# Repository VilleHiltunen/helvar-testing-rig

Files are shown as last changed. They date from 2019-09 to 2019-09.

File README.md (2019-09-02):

# helvar-testing-rig

This repository is for holding software and other project artifacts from the Aalto-University protopaja 2019 course
from project group 4. Everything here is under the Creative Commons Attribution 4.0 International License, with two 
exceptions: The KiCAD Arduino board symbols and footprints which are licensed under LGPL under the name of 
Nicholas Parks Young at https://github.com/Alarm-Siren/arduino-kicad-library. The original readme can be found in 
the MegaShield folder.

The second exception is the software code, which is written under the MIT license, and is totally free for grabs.

NOTE: There is a current (01.09.2019) bug in the Windows Arduino AVR compiler, so the Arduino mega code might not compile
with the latest board definitions. This can be fixed by downgrading the board definitions from the boards manager. See:
https://arduino.stackexchange.com/questions/58495/strange-compiler-error-segmentation-fault

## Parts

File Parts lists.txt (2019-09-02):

Part lists
Frame:
4x 800mm length piece
4x 900mm length piece
4x 1200mm length piece
4x  3-way corner connector pieces
12x M8x30 hex-key bolts
4x plastic covers for 3-way corner pieces
8x 90° profile connector pieces
4x profile end cover pieces

Movement system:
2x Trinamic PD42-3-1141
1x some stepper motor found at sähköpaja
2x sliders for i-type aluminium profile
6x micro switches for limit switches
35mm Jopo quick release seat fastener
400*17mm aluminium pipe
15.5*25*8mm Linear bearing
4x 15*24*8mm Linear bearing
6x 24 tooth 3M pulleys with 8mm bore
2x 24 tooth 3M pulleys with 6mm bore
2x 6mm into 5mm pulley bore reducer
3M 88 tooth timing belt
7m piece of 3M timing belt cut into suitable length pieces
2x 915*8mm round steel shaft
2x 850*8mm round steel shaft
891*8mm round steel shaft
108*8mm round steel shaft
15*8mm round steel shaft
2x aluminium mounts for support rail
3d printed pieces (see sensor_testing_rig_asm.stp for details)
3mm acrylic laser cut pieces (see sensor_testing_rig_asm.stp for details)
Lots of nuts and bolts

Testin unit:
3 mm acrylic (plastic).
0.6 mm PCB
Pin header 1*5 (R2.54) 
P0900 analog micro servo (K-Power).
Aluminium rod (diameter 19 mm or larger).
33 ohm resistor (Royal Ohm).
3 mm threaded rod (steel).
2x M2*10mm screw
2x M2 nut
2x M3*4mm screw
4x M3 nyloc nut
2x M4*20mm screw (countersunk head)
M4 nyloc nut
M4 nylon tightening nut
small zip tie
heat-shrink tubing
0.8 mm steel wire (to attach head to the servo) 
insulated copper wire
3x small neodym magnets

Base plate:
64x avx 3 way 9155 standard battery connector
32x 0.5A reed switch
32x 1A reed switch
64 magnets
4x backbone pcb
32x mounting slot pcb
8 core 2.54 pitch flat cable
32 core 1.27 pitch flat cable
cable
laser cut acrylic pieces
32x cat shaped handles

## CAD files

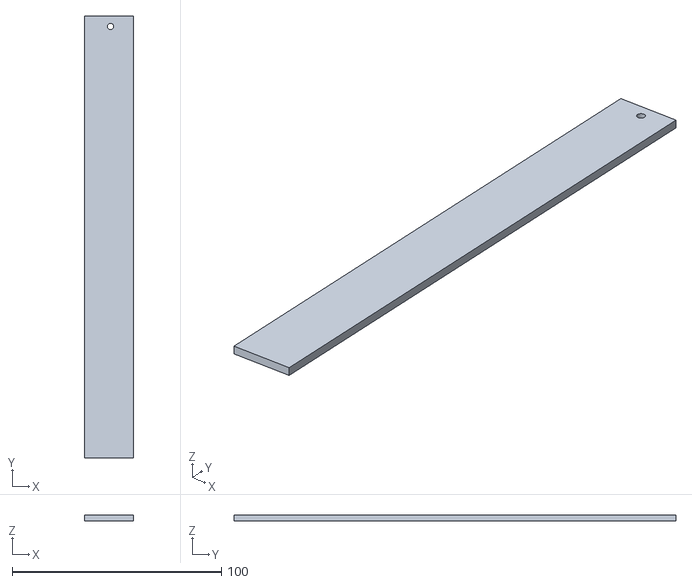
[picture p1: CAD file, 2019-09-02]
Board_stl/Assembly 1 - Part 4.stl
23.5 x 211.0 x 3.00

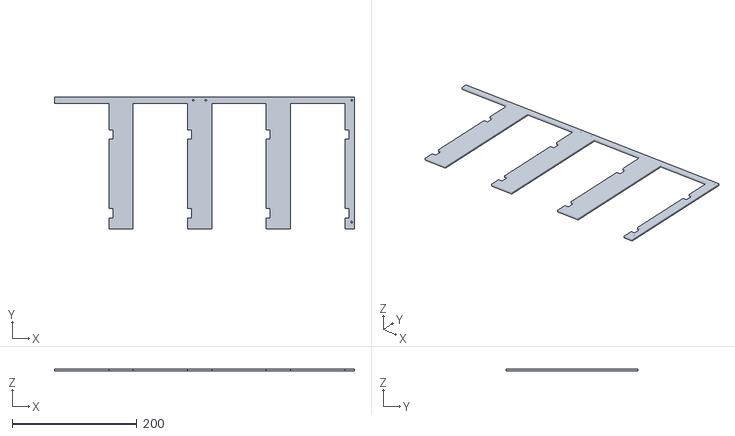
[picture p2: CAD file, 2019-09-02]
Board_stl/Assembly 1 - Part 2.stl
480.5 x 211.0 x 3.00

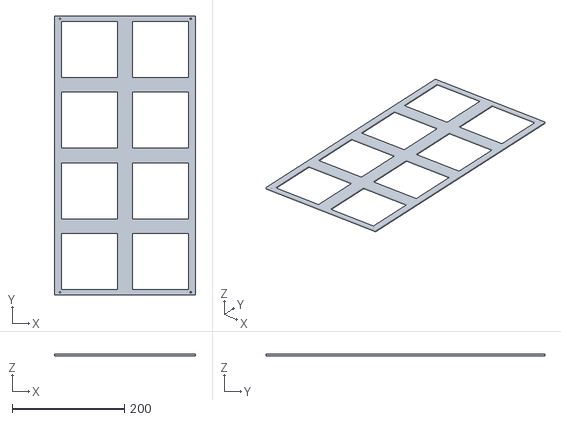
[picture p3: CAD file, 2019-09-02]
Board_stl/Assembly 1 - Part 6.stl
252.0 x 498.0 x 3.00

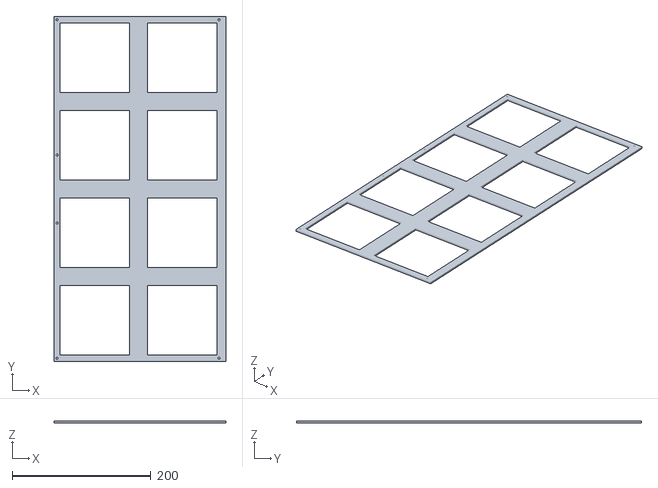
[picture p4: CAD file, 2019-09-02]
Board_stl/Assembly 1 - Part 5.stl
248.0 x 498.0 x 3.00

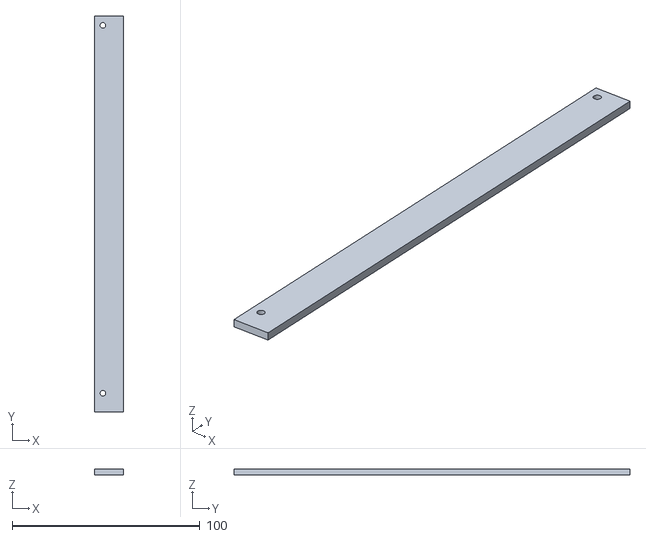
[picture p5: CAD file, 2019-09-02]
Board_stl/Assembly 1 - Part 3.stl
15.5 x 211.0 x 3.00

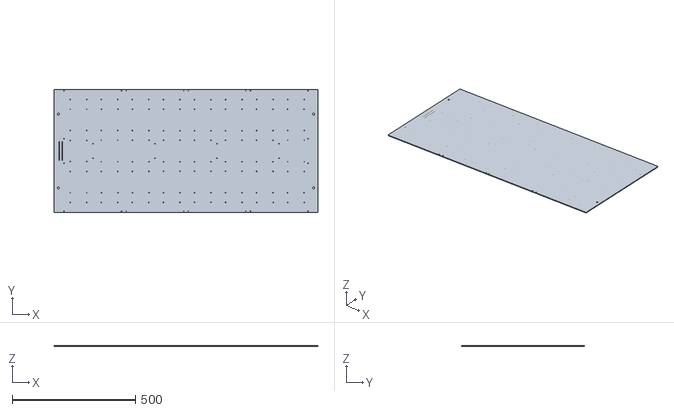
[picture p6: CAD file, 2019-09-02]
Board_stl/Assembly 1 - Part 1.stl
1072.0 x 498.0 x 3.00

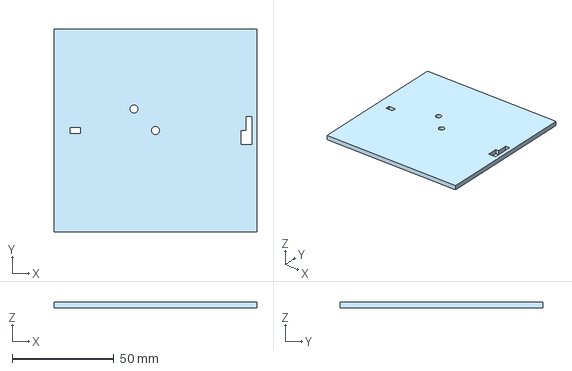
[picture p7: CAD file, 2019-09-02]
Testing_unit/Base/upper_plate.step
100.0 x 100.0 x 3.00 mm

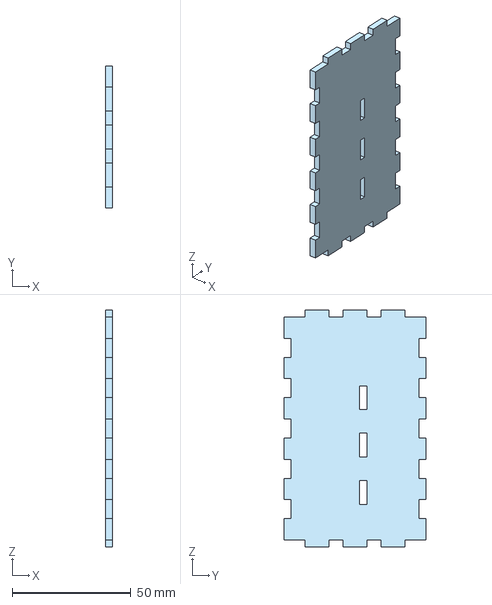
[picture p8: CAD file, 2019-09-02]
Testing_unit/Body/Body_100mm/side_100mm.step
3.00 x 60.0 x 100.0 mm

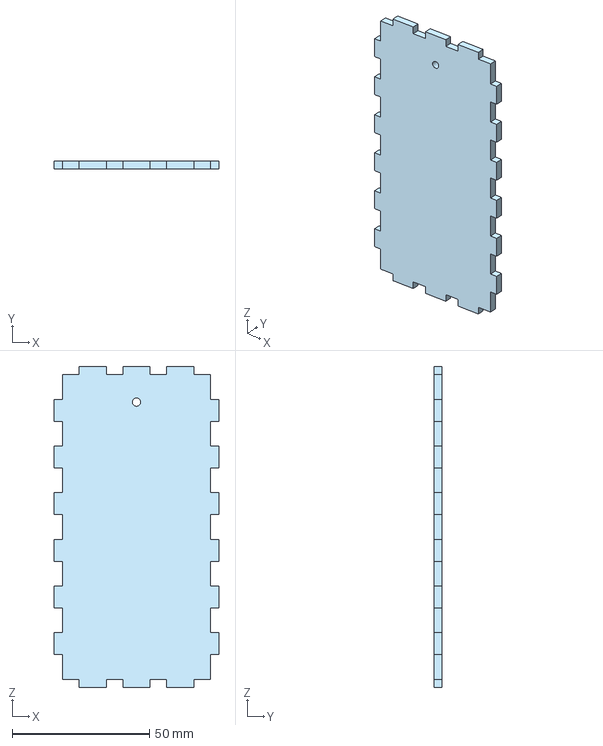
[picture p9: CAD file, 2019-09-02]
Testing_unit/Body/Body_117mm/front_117mm.step
60.0 x 3.00 x 117.0 mm

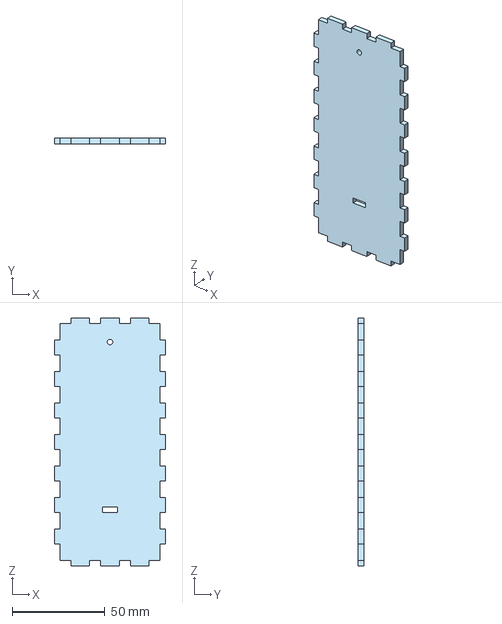
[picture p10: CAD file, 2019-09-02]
Testing_unit/Body/Body_134mm/back_134mm.step
60.0 x 3.00 x 134.0 mm

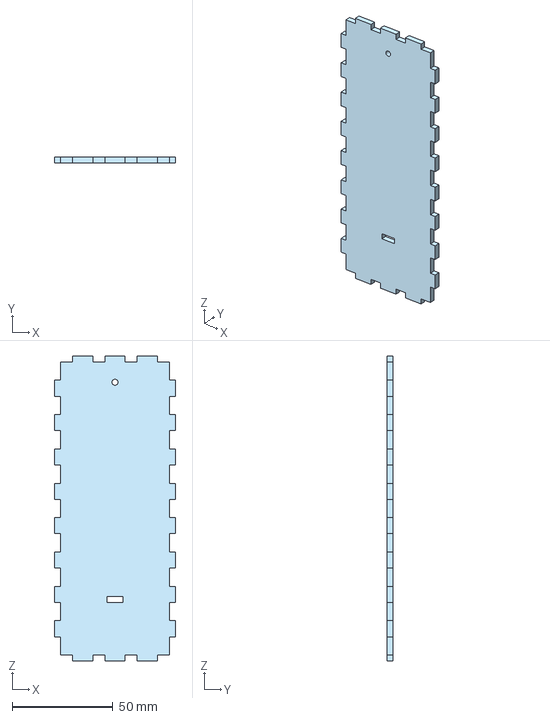
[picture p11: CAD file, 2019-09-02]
Testing_unit/Body/Body_151mm/back_151mm.step
60.0 x 3.00 x 151.0 mm

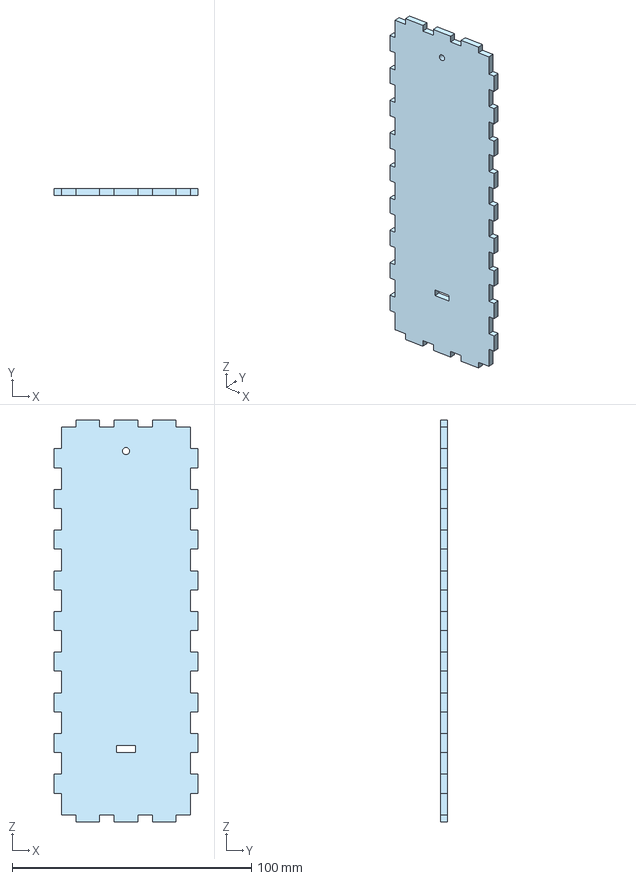
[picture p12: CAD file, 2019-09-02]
Testing_unit/Body/Body_168mm/back_168mm.step
60.0 x 3.00 x 168.0 mm

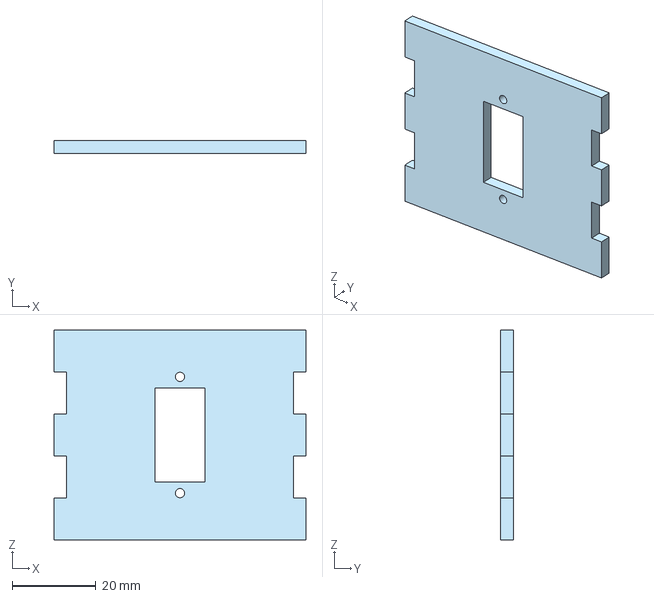
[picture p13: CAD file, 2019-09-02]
Testing_unit/Body/Common parts/servo_holder.step
60.0 x 3.00 x 50.0 mm

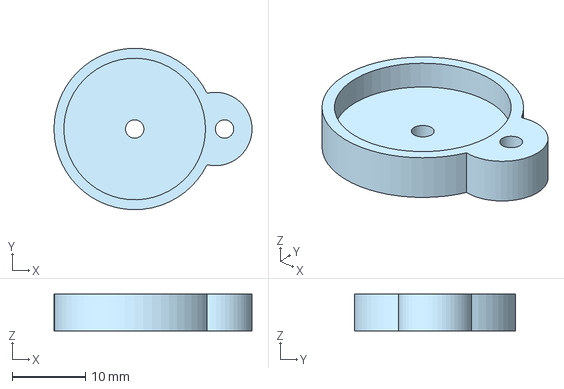
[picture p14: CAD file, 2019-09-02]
Testing_unit/Head/cap.step
27.0 x 22.0 x 5.00 mm

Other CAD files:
frame_cad/sensor_mounting_plate.stp
Testing_unit/Base/lower_plate.step
Testing_unit/Body/Body_100mm/back_100mm.step
Testing_unit/Body/Body_117mm/back_117mm.step
Testing_unit/Body/Body_100mm/front_100mm.step
Testing_unit/Body/Body_117mm/side_117mm.step
Testing_unit/Body/Body_134mm/front_134mm.step
Testing_unit/Body/Body_134mm/side_134mm.step
Testing_unit/Body/Body_151mm/front_151mm.step
Testing_unit/Body/Body_151mm/side_151mm.step
Testing_unit/Body/Body_168mm/front_168mm.step
Testing_unit/Body/Body_168mm/side_168mm.step
Testing_unit/Body/Common parts/bottom_plate.step
Testing_unit/Body/Common parts/top_plate.step
Testing_unit/Head/head.step
Testing_unit/Head/head_holder.step
frame_cad/M8_hex_nut_holder_for_aluminium_profile.stl
frame_cad/M8_hex_nut_holder_for_aluminium_profile.stp

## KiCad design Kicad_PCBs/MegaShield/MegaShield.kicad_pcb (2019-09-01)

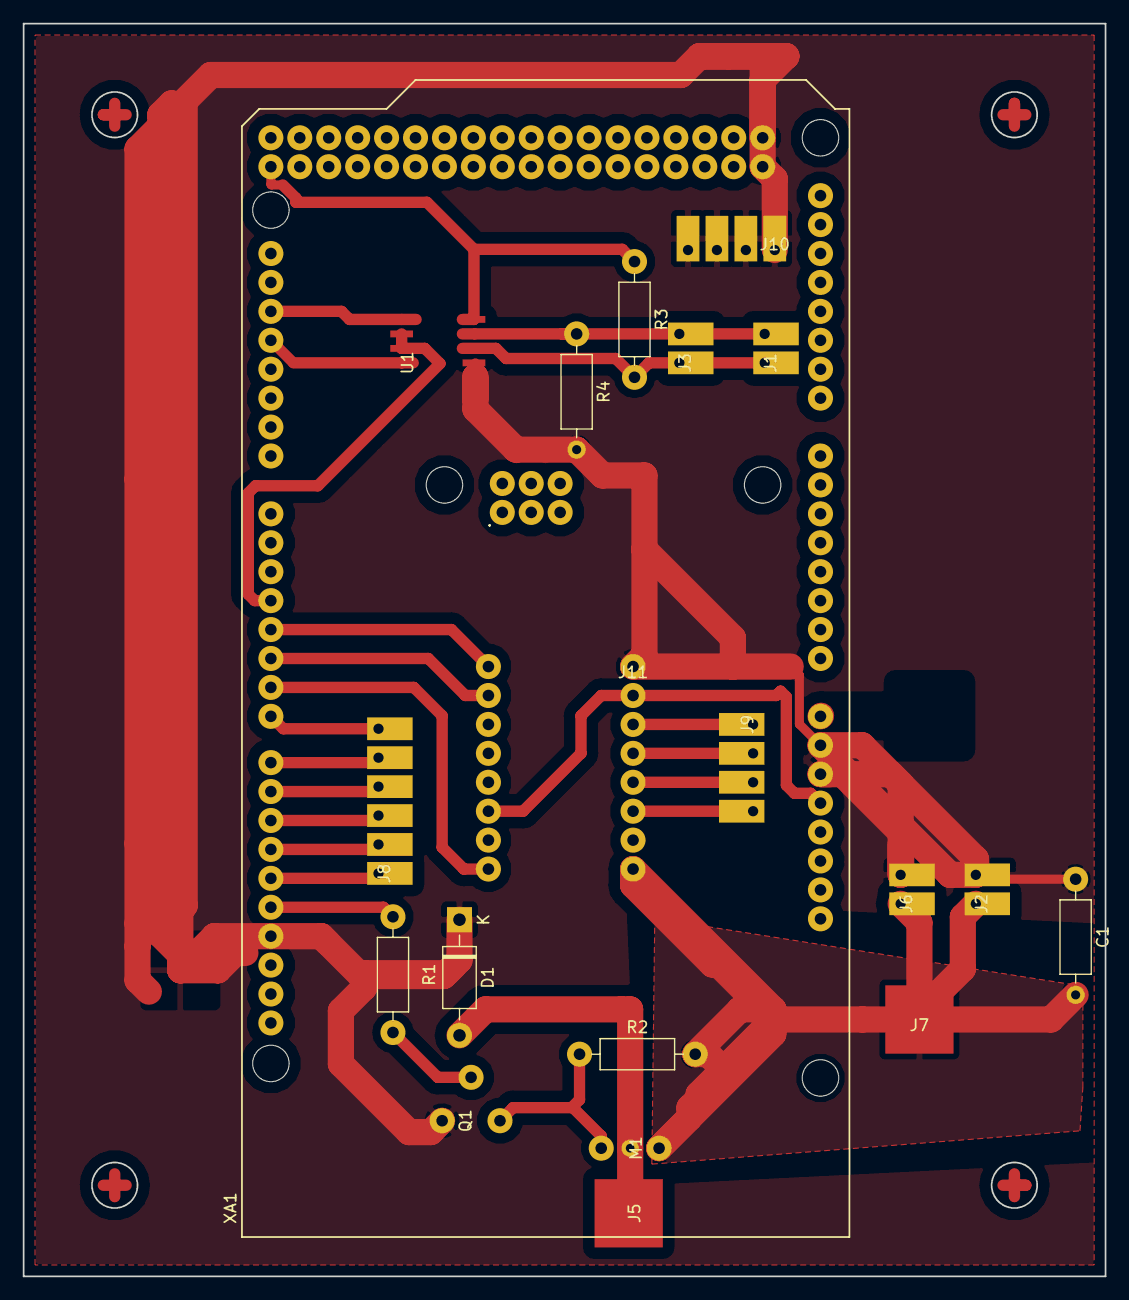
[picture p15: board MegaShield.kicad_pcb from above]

Board: 2 copper layers, 95.0 x 110.0 mm, 20 parts (0 on the bottom side), 25 nets.

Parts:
C1: 47u; R_Axial_DIN0207_L6.3mm_D2.5mm_P10.16mm_Horizontal
D1: DIODE; D_DO-41_SOD81_P10.16mm_Horizontal
J1, J3: rs485conn; 2_2.54
J2: Ypow; 2_2.54
J5: HeatingOut; VinPad
J6: Xpow; 2_2.54
J7: 12V_VIN; VinPad
J8: SensorLimits; 6_2.54
J9: SenStepper; 4_2.54
J10: limitSwitches; 4_2.54
J11: tmc2208; StepStick
M1: FQP27P06; MOSFET
Q1: 2N3904; BJT
R1: 10k; R_Axial_DIN0207_L6.3mm_D2.5mm_P10.16mm_Horizontal
R2: 1k; R_Axial_DIN0207_L6.3mm_D2.5mm_P10.16mm_Horizontal
R3, R4: R; R_Axial_DIN0207_L6.3mm_D2.5mm_P10.16mm_Horizontal
U1: MAX1487E; NSOIC-8
XA1: Arduino_Mega2560_Shield

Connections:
5V: J11.2, J11.14, R3.1, U1.8, XA1.5V1, XA1.5V3, XA1.5V4
12V: C1.2, J2.1, J6.1, J7.1, J11.8, M1.3, R2.2
DIR: J11.9, XA1.D4
DR: U1.2, U1.3, XA1.D3
EN: J11.16, XA1.D6
GND: C1.1, D1.1, J2.2, J6.2, J10.1, J10.2, J10.3, J10.4, J11.1, Q1.1, R4.2, U1.5, XA1.GND1, XA1.GND2, XA1.GND3, XA1.GND5, XA1.GND6
HEAT: R1.1, XA1.D13
unnamed: D1.2, J5.1, M1.1
unnamed: J1.1, J3.1, R3.2, U1.6
unnamed: J1.2, J3.2, R4.1, U1.7
unnamed: J9.1, J11.3
unnamed: J9.2, J11.4
unnamed: J9.3, J11.5
unnamed: J9.4, J11.6
unnamed: M1.2, Q1.3, R2.1
unnamed: Q1.2, R1.2
unnamed: U1.1, XA1.D18
unnamed: U1.4, XA1.D19
SEN_LL: J8.5, XA1.D8
SEN_RL: J8.6, XA1.D7
STEP: J11.10, XA1.D5
X_LL: J8.3, XA1.D10
X_RL: J8.4, XA1.D9
Y_LL: J8.1, XA1.D12
Y_RL: J8.2, XA1.D11

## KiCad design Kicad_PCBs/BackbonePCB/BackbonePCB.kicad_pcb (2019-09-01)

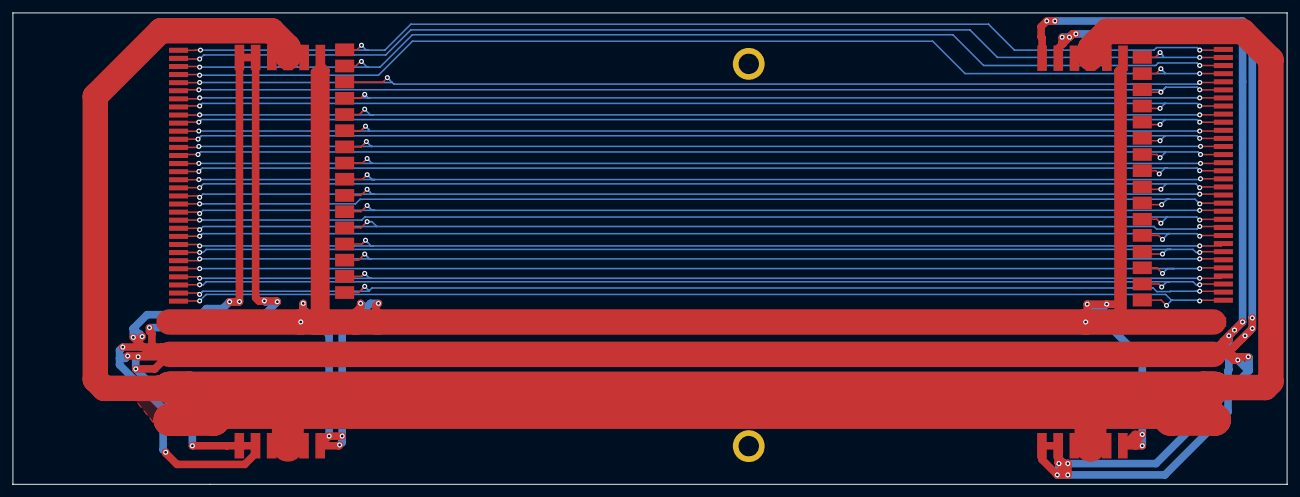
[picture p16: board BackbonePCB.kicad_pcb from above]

Board: 2 copper layers, 200.0 x 74.0 mm, 14 parts (0 on the bottom side), 35 nets.

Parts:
H1, H2: MountingHole; Screw_Hole
J1, J2, J7, J8: Conn_01x02_Female; SMD_Connector_2X
J3, J4, J5, J6: Conn_01x06_Female; SMD_Connector_6X
J9, J12: Conn_01x32_Female; Connector_32x
J10, J11: Conn_01x16_Female; Connector_16x

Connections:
/5V: J2.2, J3.6, J4.1, J5.6, J6.1, J8.1
/12V: J2.1, J3.1, J3.2, J4.5, J4.6, J5.1, J5.2, J6.5, J6.6, J8.2
/GND: J1.1, J1.2, J3.3, J3.4, J3.5, J4.2, J4.3, J4.4, J5.3, J5.4, J5.5, J6.2, J6.3, J6.4, J7.1, J7.2
unnamed: J9.32, J10.1, J12.1
unnamed: J9.30, J10.2, J12.3
unnamed: J9.28, J10.3, J12.5
unnamed: J9.26, J10.4, J12.7
unnamed: J9.24, J10.5, J12.9
unnamed: J9.22, J10.6, J12.11
unnamed: J9.20, J10.7, J12.13
unnamed: J9.18, J10.8, J12.15
unnamed: J9.16, J10.9, J12.17
unnamed: J9.14, J10.10, J12.19
unnamed: J9.12, J10.11, J12.21
unnamed: J9.10, J10.12, J12.23
unnamed: J9.8, J10.13, J12.25
unnamed: J9.6, J10.14, J12.27
unnamed: J9.4, J10.15, J12.29
unnamed: J9.2, J10.16, J12.31
unnamed: J9.1, J11.1, J12.32
unnamed: J9.3, J11.2, J12.30
unnamed: J9.5, J11.3, J12.28
unnamed: J9.7, J11.4, J12.26
unnamed: J9.9, J11.5, J12.24
unnamed: J9.11, J11.6, J12.22
unnamed: J9.13, J11.7, J12.20
unnamed: J9.15, J11.8, J12.18
unnamed: J9.17, J11.9, J12.16
unnamed: J9.19, J11.10, J12.14
unnamed: J9.21, J11.11, J12.12
unnamed: J9.23, J11.12, J12.10
unnamed: J9.25, J11.13, J12.8
unnamed: J9.27, J11.14, J12.6
unnamed: J9.29, J11.15, J12.4
unnamed: J9.31, J11.16, J12.2

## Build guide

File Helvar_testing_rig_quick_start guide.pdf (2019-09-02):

# Helvar testing rig quick start guide

Ville Hiltunen
02.09.2019
1. Plug both the 12V and 5V power adapters into the machine. Plugging the connectors into the wrong plugs won’t cause electrical problems, but the machine won’t turn on.
2. Turn on the power switch. The xy-plane stepper motors should now blink their LEDs. If not, check power adapters.
3. Connect the Arduino to the device.
4. Open a serial connection with Arduino. Baud rate should be 38400 unless modified. The Arduino serial monitor has been tested to work, but in theory any serial terminal should work.
5. The serial should display formatted replies from the motors. If not, you’ve ran into the mysterious bug that blocks communication on the RS-485 line. Try again later and/or after cycling the device power.
6. If replies are displayed on the screen, insert the command “homesen” (without the quotes) to home the sensor header. All commands should have a newline (‘\n’) as the end character.
7. Next, insert command “homexy” to home the XY-plane.
8. The device should now be ready to use! The command format for commands with arguments is cmd(arg1,arg2,...,argx).
9. Remove a cover from a slot, then place a model to the slot. The magnets should pull the model and the connector together. Use srva(slotnumber) to add the model. If everything went right, the servo should be waving back and forth and heating up. If not, either there is a problem with the connection or the model is misplaced. Use srvl to list servo locations. Note that the first slot starts from the corner where the Arduino usb plug is connected.

10.Try more commands from the list below.

## Command list and descriptions:

## Main functionalities:

Command word | Arguments | Description
homesen | 0 | Homes the sensor header to the middle position, which is set to be angle 0.
homexy | 0 | Homes the xy-plane. Note: This command will flush the command buffer, and while the device is homing, no new commands will be read from the buffer. At the end of homing, the sensor head will be placed above the corner of the simulated room, and this position will be considered (0,0) for millimeter coordinates.
xypos | 2 | Run the sensor head to a xy-position in millimeters. Argument 1: x-axis from 0 to 1000. Argumen 2: y-axis from 0 to 500. Example input: xypos(100,250)
sen | 1 | Turns the sensor head to the given angle. Input: Sensor angle relative to the 0 position from -125 to 125. If the sensor is unhomed, the sensor head might overshoot and hit a limit switch. If this happens, the device should be rehomed. Example input: sen(50)
help | 0 | Lists the commands, arguments and constraints to the serial line.
heatc | 1 | Sets the heating power as a percentage between 0 and 100. Example input: heatc(15)
heatl | 0 | Lists the current heating power.
heati | 0 | Activates full heating power for 60 seconds.
srva | 1 | Adds a model to the given slot. Accepts inputs from 1-32.

| | Example input: srva(1)
srvr | 1 | Removes a model from the given slot. Input: 1 to 32 or -1. Inputting -1 purges all servos. Example input: srvr(1) Bug: Current code allows 0 as a valid input, which results in an access outside of array bounds.
srvl | 0 | Lists the positions of models and speeds and hold delays of all slots.
srvs | 2 | Changes model swaying speed. Argument 1: The slot number from 1 to 32 or -1 for all models. Argument 2: The speed percentage from 1 to 100. The command displays the actual microsecond delay after input. Example input: srvs(-1,50) Bug: Current code allows 0 as a valid input, which results in an access outside of array bounds.
srvm | 2 | Sets the model to the given movement state. Argument 1: The slot number from 1 to 32 or -1 for all models. Argument 2: The new state, either 0 or 1. 0 for constant sway, 1 for delay at the max and min angles. Example input: srvm(1,1) Bug: Current code allows 0 as a valid input, which results in an access outside of array bounds.
srvh | 2 | Changes model holding delay. Default setting holds the model in place for 3 seconds at minimum and maximum angles. Argument 1: The slot number from 1 to 32 or -1 for all models. Argument 2: The hold in milliseconds from 5 to 30000. The command displays the actual microsecond delay after input. Example input: srvh(-1,2000)

Bug: Current code allows 0 as a valid input, which results in an access outside of array bounds.

## Trinamic stepper motor commands:

These commands are very similar to the Trinamic PD42 stepper commands and speak directly to the rig stepper motors. Care should be taken with these functions, as they might alter the behavior of the program.

Command word | Argument s | Description
mst | 1 | Stops the target motor. Argument is the motor address, either 1 or 2.
gap | 2 | Asks for a certain axis parameter from the driver. Argument 1 is the motor address, 1 or 2. Argument 2 is the command type, aka which parameter we are interested in , from 0 to 255. See trinamic documentation in references for details.
sap | 3 | Sets a certain axis parameter on the driver. Argument 1 is the motor address, 1 or 2. Argument 2 is the command type, aka which parameter we are interested in, from 0 to 255. Argument 3 is the value we want to set the parameter to. See trinamic documentation in references for details.
ggp | 3 | Asks for a certain global parameter from the driver. Argument 1 is the motor address, 1 or 2. Argument 2 is the command type, aka which parameter we are interested in, from 0 to 255. Argument 3 is the memory bank from 0 to 3. See trinamic documentation in references for details.
sgp | 4 | Sets a certain global parameter in the driver. Argument 1 is the motor address, 1 or 2. Argument 2 is the command type, aka which parameter we are interested in, from 0 to 255. Argument 3 is the memory bank from 0 to 3. Argument 4 is the new value for the parameter.

| | See trinamic documentation in references for details.
rfs | 2 | Controls the homing of the target motor. Argument 1 is the target motor, 1 or 2. Argument 2 is the command. 0 for starting, 1 for stopping and 2 for asking for status. See trinamic documentation in references for details.
exp | 5 | Not a true trinamic command, rather this command emulates a totally free form 8 byte package for sending to the motor drivers. Consult the firmware documentation and know exactly what you are doing before using this. Argument 1 is the target motor address. Argument 2 is the instruction number. Argument 3 is the type number. Argument 4 is the motor or bank number. Argument 5 is the value. Checksum is calculated automatically for the user.

## References

Trinamic PD42 stepper page. See the firmware manual for more info on stepper commands: https://www.trinamic.com/products/drives/stepper-pandrives-details/pd42-x-1141/

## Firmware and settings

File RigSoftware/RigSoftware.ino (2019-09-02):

/*
 * Written by Ville Hiltunen (2019) villejhiltunen@gmail.com under MIT license.
 */

#include "RigSoftware.h"
#include <Servo.h>

/*
 * Command definitions here. 
 * Type 1 corresponds to PANdrive stepper functions, 
 * Type 2 is servo related functions
 * Type 3 is for sensor movement
 * Type 4 is heating related functions
 * Type 5 is the type for the main composite functionalities that issue commands themselves and other miscallaneous control commands.
 * 
 * If you wish to add your own ones, add it here, go to the function that handles it and add a handler.
 * Also increment the COMMAND_LIST_SIZE by one. PANdrive stepper functions have a universal handler, provided a prefilled MI
 * and arg field is provided.
 * 
 * CMD is the command word recognized by the parser.
 * 
 * Len is the number of letters in the command word.
 * 
 * Args is the number of arguments the command has
 * 
 * Arg_Field is strictly for PANdrive stepper functions and guides which argument fills which datafield in the 9 byte command.
 *    arg_Field should be the size of the number of arguments for the command. Argument 0 uses the index of arg_field[0] and so forth.
 *    Index 0 is the machine address, Index 1 is the command type, Index 2 is the type specification, Index 3 is the motor bank and Index 4 is the 4-byte value.
 *    Check sendMotorCommand function for more details.
 *    
 * Lower and higher constraints limit the allowed user input between them. There should be as many constraints as there are arguments.
 * 
 * Prefilled MI is a motorInfo struct that has the correct command number associated with the command according to PANdrive manual. Not used for non PD-stepper functions.
 */
commandWordInfoStruct commandWordInfo[COMMAND_LIST_SIZE] = {
//Type	Cmd					Len	Args	arg_Field			Lower constraints			Higher constraints		Prefilled MI
	//{1,		"ror",			3,	2,		{0,4,},				{1,-2047,},						{2,2047,},						{0,1,},},
	{1,		"mst",			3,	1,		{0,},					{1,},									{2,},									{0,3,},},
	{1,		"mvp",			3,	2,		{0,4,},				{1,-2147483648,},			{2,2147483647,},			{0,4,},},
	{1,		"gap",			3,	2,		{0,2,},				{1,},									{2,255,},							{0,6,},},
	{1,		"ggp",			3,	3,		{0,2,3,},			{1,},									{2,255,3,},						{0,10,},},
	{1,		"sgp",			3,	4,		{0,2,3,4},		{1,0,0,-2147483647},	{2,255,3,2147483647},	{0,9,},},
	{1,		"sap",			3,	3,		{0,2,4,},			{1,0,-2147483648,},		{2,255,2147483647,},	{0,5,},},
	{1,		"rfs",			3,	2,		{0,2,},				{1,},									{2,255,3,},						{0,13,},},
	{1,		"stap",			4,	2,		{0,2,},				{1,},									{2,255,},							{0,7,},},
	{2,		"srva",			4,	1,		{0},					{1,},									{32,},},
	{2,		"srvr",			4,	1,		{0},					{-1,},								{32,},},
	{2,		"srvs",			4,	2,		{0,2,},				{-1,1,},							{32,100,},},
	{2,		"srvl",			4,	0,		},
	{2,		"srvm",			4,	2,		{0,},					{-1,0,},							{32,1,},},
	{2,		"srvh",			4,	2,		{0,},					{-1,5,},							{32,30000,},},
	{3,		"sen",			3,	1,		{0},					{-125,},							{125,},},
	{4,		"heatc",		5,	1,		{0},					{0},									{100},},
	{4,		"heatl",		5,	0,		},
	{4,		"heati",		5,	0,		},
	{5,		"xypos",		5,	2,		{0},					{0,0,},								{1000,500,},/*{-2147483648,-2147483648,},		{2147483647,2147483647,},*/},
	{5,		"homexy",		6,	0,		},
	{5,		"homesen",	7,	0,		},
	{5,		"help",			4,	0,		},
	{1,		"exp",			3,	5,		{0,1,2,3,4},	{0,0,0,0,-2147483647},{255,255,255,255,2147483647},					{0,},},
};

//Buffers, flags and struct inits.
char cmdBuffer[CMD_BUFFER_LEN];
char replyBuffer[CMD_BUFFER_LEN];
commandInfo cmdInfo;
commandInfo replyInfo;
int sensorTasklist[SENSOR_TASKLIST_LEN];
unsigned long timers[TIMER_LEN];
int replyFlag;
int servoModeFlag;
ringBufferInfoStruct ringBufferInfo;
servoInfoStruct servoInfo;
heatingInfoStruct heatingInfo;
homeInfoStruct homeInfo;

void setup() {
	Serial.begin(38400);
	Serial1.begin(38400);
	while (!Serial) {
		;
	}
  pinMode(DR_PIN, OUTPUT);
  pinMode(SENSOR_ENABLE, OUTPUT);
  pinMode(HEATING_PIN, OUTPUT);
  pinMode(SENSOR_DIR, OUTPUT);
  pinMode(SENSOR_STEP, OUTPUT);
  pinMode(SENSOR_LSWITCH, INPUT_PULLUP);
  pinMode(SENSOR_RSWITCH, INPUT_PULLUP);
  // Sadly there was no time to add the xy limit switches. RIP
  //pinMode(X_RSWITCH, OUTPUT);
  //pinMode(X_LSWITCH, OUTPUT);
  digitalWrite(SENSOR_ENABLE, HIGH);
  digitalWrite(SENSOR_DIR, LOW);
  digitalWrite(SENSOR_STEP, LOW);
	digitalWrite(DR_PIN,LOW);
  // Setting default values
	sensorTasklist[SENSOR_MAX] = 300;
	sensorTasklist[SENSOR_MIN] = -300;
	heatingInfo.heatingActual = map(HEATING_DEFAULT_PERCENT,0,100,0,200);
	heatingInfo.heatingPercent = HEATING_DEFAULT_PERCENT;
	cmdInfo.cmdBuffer = cmdBuffer;
	replyInfo.cmdBuffer = replyBuffer;
  // We initialize each servo position with -1, which means no servo.
  // Also, we attach and detach each servo position to prevent floating servo signals at startup.
	for (int i = 0; i < SERVO_SLOTS; i++) {
    servoInfo.servos[0].attach(i+1+SERVO_PIN_OFFSET);
		servoInfo.slots[i] = -1;
    delay(20);
    servoInfo.servos[0].detach();
	}
	for (int i = 0; i < SERVO_AMOUNT; i++) {
		servoInfo.states[i] = 1;
		servoInfo.delays[i] = SERVO_DEFAULT_DELAY_U;
		servoInfo.holdDelays[i] = SERVO_DEFAULT_HOLD_DELAY;
	}
	// Actual initialization of the machine. We set the proper speed for the machine, set the heating to max for 60 seconds
  // And we home the steppers
  injectCommand(ringBufferInfo, "heati");
  injectCommand(ringBufferInfo, "sap(1,4,400)");
  injectCommand(ringBufferInfo, "sap(2,4,200)");
  /*
  injectCommand(ringBufferInfo, "sap(1,194,2000)");
  injectCommand(ringBufferInfo, "sap(2,194,2000)");
  */
  /*
  injectCommand(ringBufferInfo, "sap(1,140,7)");
  injectCommand(ringBufferInfo, "sap(2,140,7)");
  */
  /*
  injectCommand(ringBufferInfo, "sap(1,140,7)");
  injectCommand(ringBufferInfo, "sap(2,140,7)");
  */
  //injectCommand(ringBufferInfo, "homexy");
	timers[LOOP_TIMER] = millis();
}

void loop() {
	// Check if serial line has data for us. It will be stored in the cmdInfo struct.
	if (!cmdInfo.newCmd && !(homeInfo.homeXFlag || homeInfo.homeYFlag)) {
		cmdInfo = getCommand(cmdInfo, Serial);
		if (replyInfo.errorNmbr) {
			// The command or the buffer had some error. Print complaint.
	  	Serial.print("Command buffer error -	");
	  	Serial.println(cmdInfo.errorNmbr);
	  	cmdInfo.errorNmbr = 0;
	  	cmdInfo.newCmd = 0;
	  	cmdInfo.dataIndex = 0;
	  }
	}
  // Check if the flag for a new command has been raised. (data contained a newline)
	if (cmdInfo.newCmd && !(homeInfo.homeXFlag || homeInfo.homeYFlag)) {
		// We have a new command. Copy it to our command ring buffer.
		injectCommand(ringBufferInfo,cmdInfo.cmdBuffer);
		cmdInfo.newCmd = 0;
		cmdInfo.dataIndex = 0;
	}
	// Process a command from the ringbuffer if there are any and we are not waiting.
	// Wait is issued when a command is sent to the XY-plan motors to reduce communication
	// errors.
	if (!replyFlag && ringBufferInfo.commandCount > 0) {
		String incCommand = grabRingBufferCommand(ringBufferInfo);
		parseResult result = evaluateCommand(incCommand, commandWordInfo, Serial);
		if (result.errorStatus) {
			Serial.print("Parsing error, code: ");
			Serial.println(result.errorStatus);
      if (result.errorStatus == E_COMMAND_MALFORMED) {
        Serial.println("Command malformed");
      }
			//Serial.println("Send command errl to list codes.");
		}
		else {
			switch (commandWordInfo[result.commandIndex].commandType) {
				case 1:
					sendMotorCommand(timers, result, commandWordInfo);			
					break;			
				case 2:
					sendServoCommand(timers, result, commandWordInfo, servoInfo, Serial);
					break;			
				case 3:
					sendSensorCommand(timers, result, commandWordInfo, sensorTasklist, Serial);
					break;		
				case 4:
					sendHeatingCommand(timers, result, commandWordInfo, heatingInfo, Serial);
					break;
				case 5:
					sendControlCommand(timers, result, commandWordInfo, ringBufferInfo, Serial, homeInfo, sensorTasklist);
					break;	
				default:
					Serial.print("Unknown command type.");
			}		
			replyFlag = 1;
		}
	}

	// Here we process the wait timer. Once the timer is ready (or the processed command
	// set no timer, we display whatever reply we got back to user and allow further
	// command processing.
  if (timers[REPLY_TIMER] + REPLY_DELAY < timers[LOOP_TIMER]) {
	  replyInfo = getReply(replyInfo, Serial1);
	  if (replyInfo.errorNmbr) {
	  	Serial.println("Reply buffer error, attempting to clear buffer."); 	
	  	replyInfo.dataIndex = 0;
	  	delay(20);
	  	while (Serial1.available() > 0) {
	  		char trashCan = Serial1.read();
	  	}
	  	Serial.print("Buffer error code:  ");
	  	Serial.println(replyInfo.errorNmbr);
	  	replyInfo.errorNmbr = 0;
	  	Serial.println("Displaying mangled reply: ");
	  	replyInfo.newCmd = 1;  	
	  }
	  if (replyInfo.newCmd) { 
	  	if (homeInfo.homeXFlag && homeInfo.replyCount > 0) {
        // If we are ignoring repliess, do so and subtract from the reply count.
	  		homeInfo.replyCount -= 1;
	  	}
	  	if (homeInfo.homeXFlag && homeInfo.replyCount == 0) {
	  		if (((long*)(replyInfo.cmdBuffer))[1] == 0 && replyInfo.cmdBuffer[3] == 13 && replyInfo.cmdBuffer[1] == 1) {
          // If we are not ignoring replies and were are homing, we will ask if x-axis is homed until it is
          // Then we do the same for y-axis
	  			homeInfo.homeXFlag = 0;
	  			homeInfo.homeYFlag = 1;
	  		}
	  	}
	  	else if (homeInfo.homeYFlag) {
	  		if (((long*)(replyInfo.cmdBuffer))[1] == 0 && replyInfo.cmdBuffer[3] == 13 && replyInfo.cmdBuffer[1] == 2) {
          // If we are here, y-axis homing is done as well now
	  			homeInfo.homeYFlag = 0;
          // At the end of the homing sequence, we put the sensor over the corner of the board.
          injectCommand(ringBufferInfo, "xypos(0,0)");
	  		}
	  	}
	    displayReply(replyInfo,Serial);
	    replyInfo.dataIndex = 0;
	    replyInfo.newCmd = 0;
	  }
  	replyFlag = 0;
  }
	// Sensor loop executes steps if a command added steps to be taken into the tasklist.
	sensorLoop(sensorTasklist, timers, homeInfo, Serial);
	// Servo loop rocks the servos back and forth, if any are attached.
  servoLoop(servoInfo,timers);
  // Loop to check if timed heating should be still active
  if (heatingInfo.heatingFlag) {
  	heatingLoop(heatingInfo,timers,Serial);
  }
  // Home loop in case we are homing
  if (homeInfo.homeXFlag || homeInfo.homeYFlag) {
  	homeLoop(ringBufferInfo, timers, homeInfo);
  }
  // Timer advancement.
  timers[LOOP_TIMER] = millis();
  timers[MICRO_LOOP_TIMER] = micros();
  // Arduino microsecond timer rolls over every 70 minutes or so.
  // When this happens, we must reset servo timers or they might get stuck.
  if (timers[MICRO_LOOP_TIMER] < timers[OLD_MICRO_TIMER]) {
  	for (int i = 0; i < SERVO_AMOUNT; i++) {
  		servoInfo.timers[i] = 0;
  	}
  }
}

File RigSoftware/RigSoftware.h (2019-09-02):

/*
 * Written by Ville Hiltunen (2019) villejhiltunen@gmail.com under MIT license.
 */

#ifndef RIGSOFTWARE_H
#define RIGSOFTWARE_H
#include <Arduino.h>
#include <Servo.h>
/*
 * User input command buffer length
 */
#define CMD_BUFFER_LEN 							32
/*
 * User input command buffer length
 */
#define CMD_RING_BUFFER_LEN 				20

/*
 * Minimum length of a command in characters
 */
#define CMD_MIN_LEN									3
/*
 * Pandrive stepper message length
 */
#define STEPPER_LEN 								9

/*
 * Error codes
 */
#define E_BUFFER_FULL 	 						111
#define E_CHECKSUM_OFF							222
#define E_COMMAND_MALFORMED					333
#define E_CONSTRAINT								444
#define E_NOTFOUND									404

/*
 * Stepper rs-485 D/R pin
 */
#define DR_PIN											3
/*
 * Heat control pin
 */
#define HEATING_PIN									13
/*
 * Maximum command arguments
 */
#define MAX_ARGS										5
/*
 * Number of motor info fields
 */
#define MI_FIELDS										5
#define MI_BYTE_LEN									8
/*
 * The number of user commands recognized by the software
 */
#define COMMAND_LIST_SIZE						23
/*
 * Timer and timing definitions
 */
#define LOOP_TIMER									0
#define SENSOR_STEP_TIMER						1
#define REPLY_TIMER									2
#define HOME_TIMER									3
#define MICRO_LOOP_TIMER						4
#define LIMIT_SWITCH_TIMER					5
#define HEATING_TIMER								6
#define OLD_MICRO_TIMER							7

#define TIMER_LEN										8

#define SENSOR_STEP_DELAY						1
#define REPLY_DELAY									250
#define HOME_DELAY									2000
// Tweak the DR_LINE_DELAY_U to control how long we wait after setting the D/R line before actually sending
// a command to the stepper motors. In earlier prototypes the D/R line reacted too slowly and the 
// first bits of the message would get cut
#define DR_LINE_DELAY_U							0
#define SERVO_DEFAULT_DELAY_U				20000
#define SERVO_UPPER_DELAY_U					30000
#define SERVO_LOWER_DELAY_U					3000
#define LIMIT_SWITCH_DELAY					1000
#define HEATING_DELAY								60000
#define SERVO_DEFAULT_HOLD_DELAY		3000						
/*
 * Sensor tasklist definitions
 */
#define SENSOR_STEPS								0
#define SENSOR_POS									1
#define SENSOR_MAX									2
#define SENSOR_MIN									3
#define SENSOR_HOME									4
#define SENSOR_TASKLIST_LEN					5

/*
 * Sensor steps to angle conversion
 */
#define STEPS_TO_ANGLE							0.45F
/*
 * XY steps to millimeter conversion
 */
#define STEPS_TO_MM									-700.0F
/*
 * Sensor home correction
 */
#define SENSOR_HOME_CORR            4
/*
 * Max number of servos and slots to put them in
 */
#define SERVO_AMOUNT								10
#define SERVO_SLOTS									32

/*
 * Servo max and min angles
 */
#define MAX_ANGLE										110
#define MIN_ANGLE										70

/*
 * XY plane stepper max and min positions
 */
#define X_OFFSET										0
#define Y_OFFSET										50

/*
 * Arduino mega pin offset for the 32 pin slot
 */
#define SERVO_PIN_OFFSET						21
/*
 * Sensor stepper pin definitions
 */
#define SENSOR_ENABLE								6
#define SENSOR_DIR									4
#define SENSOR_STEP									5
#define SENSOR_LSWITCH							8
#define SENSOR_RSWITCH							7

#define X_RSWITCH										9
#define X_LSWITCH										10
#define Y_RSWITCH										11
#define Y_LSWITCH										12

#define HEATING_DEFAULT_PERCENT			25
/*
 * Struct for holding getCommand information.
 * 
 * @param cmdBuffer			Pointer to the buffer to store incoming data
 * @param dataIndex			Holds the data index where to start in the buffer
 * @param newCmd				Flag whether a command has been completed and should be parsed
 * @param errorNmbr			Holds the error code for the command listener
 */
typedef struct 
{
	char *cmdBuffer;
	int dataIndex;
	int newCmd;
	int errorNmbr;
} commandInfo;

/*
 * This struct holds information related to homing the XY plane
 * 
 * @param replyCount      Counts downwards each time a reply is read and ignores the reply. Used for homing XY-plane
 * @param homeXFlag       Flag for x-axis homing state
 * @param homeYFlag       Flag for y-axis homing state
 * @param sensorHomeFlag  Flag for whether homing is in progress
 * @param homedFlag       Flag whether the XY-plane is homed. Disallows xypos unless set
 */
typedef struct 
{
	int replyCount;
	int homeXFlag;
	int homeYFlag;
	int sensorHomeFlag;
	int homedFlag;
} homeInfoStruct;
/*
 * This is the ring buffer for holding commands before they are executed
 * 
 * @param ringInputIndex    The index where the next command should be inserted
 * @param ringOutputIndex   The index where the next command should be read
 * @param commandCount      How many unread commands the ring buffer holds
 * @param cmdRingBuffer     Pointer to the ring buffer. This is an array of arrays
 */
typedef struct
{
  int ringInputIndex;
  int ringOutputIndex;
  int commandCount; //TODO: Handle ring buffer overflow when commandCount > CMD_RING_BUFFER_LEN
  char cmdRingBuffer[CMD_RING_BUFFER_LEN][CMD_BUFFER_LEN];
} ringBufferInfoStruct;
/*
 * This struct stores the proper datafields for sending a PANdrive stepper command
 * Note that not all fields are relevant with all commands. See PD42 firmware manual for more info
 * 
 * @param moduleAddress    Address of the motor. The motors are set to 1 and 2 but can be redefined using SAP
 * @param command          The command instruction number for the motor
 * @param commandType      The subtype of the command
 * @param motorBank        The memory bank the command targets
 * @param motorValue       Value field of the command
 */
typedef struct
{
	char moduleAddress;				//Module address
	char command;							//Command
	char commandType;					//Type
	char motorBank;						//Motor/bank
	long motorValue;
} motorInfoStruct;


/*
 * Union for accessing the motorInfoStruct via direct byte array access
 * 
 * @param bytes            byte access to the union
 * @param motorInfo        the motorInfo, as defined above
 */
typedef union {
	byte bytes[MI_BYTE_LEN];
	motorInfoStruct motorInfo;
} motorInfoUnion;

/*
 * This behemoth contains the full command format definition accepted by the command functions
 * 
 * Read the detailed usage description in the main file
 */
typedef struct {
	int commandType;
	const char* commandWord;
	int commandWordLen;
	int numOfArgs;
	int argFields[MI_FIELDS];
	long lowerConst[MI_FIELDS];
	long upperConst[MI_FIELDS];
	motorInfoUnion mi;
} commandWordInfoStruct;

/*
 * Struct to store information parsed out of a command
 */
typedef struct 
{
	int commandIndex;
	int errorStatus;
	long args[MAX_ARGS];
} parseResult;
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

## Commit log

2019-09-01 Added project files
    [BackbonePCB-B.Cu.gbr, BackbonePCB-B.Mask.gbr, BackbonePCB-B.SilkS.gbr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]
2019-09-01 Updated bunch of stuff
    [MegaShield.kicad_pcb]
2019-09-02 Added a bunch of resources
    [Assembly 1 - Part 1.stl, Assembly 1 - Part 2.stl, Assembly 1 - Part 3.stl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]
